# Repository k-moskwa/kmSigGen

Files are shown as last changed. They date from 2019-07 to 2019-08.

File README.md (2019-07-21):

# kmSigGen
DDS Generator based on AD9833 and ATMega8A with WiFi support via ESP8266-01

Main features:
* generates square (5Vp-p), sine and triangle(0.6Vp-p) waves in the ~0.1Hz to 12.5MHz frequency range (with ~0.1Hz step regulation)
* user interface based on LCD 16x2 and single rotary encoder with button
* possibility to store and recall 4 presets
* possibility to control device via TWI/I2C interface
* optional ESP8266-01 module for controlling device via WWW (e.g. from mobile phone)
* localization (available English and Polish language)
* screen saver (when available in LCD)
* easy configuration process with single conifg.h file (with possibility to disable some modules)
* project files available for AtmelStudio7 and Eclipse 

Components:
* ATmega8A MCU @ 8MHz
* AD9833/9837 assembled module @ 25MHz
* LCD 16x2 screen
* rotary encoder with button
* resistors, capacitors, connectors as defined on schematics view
Optional components:
* ESP8266-01 module
* 2 x LED (power and debug)

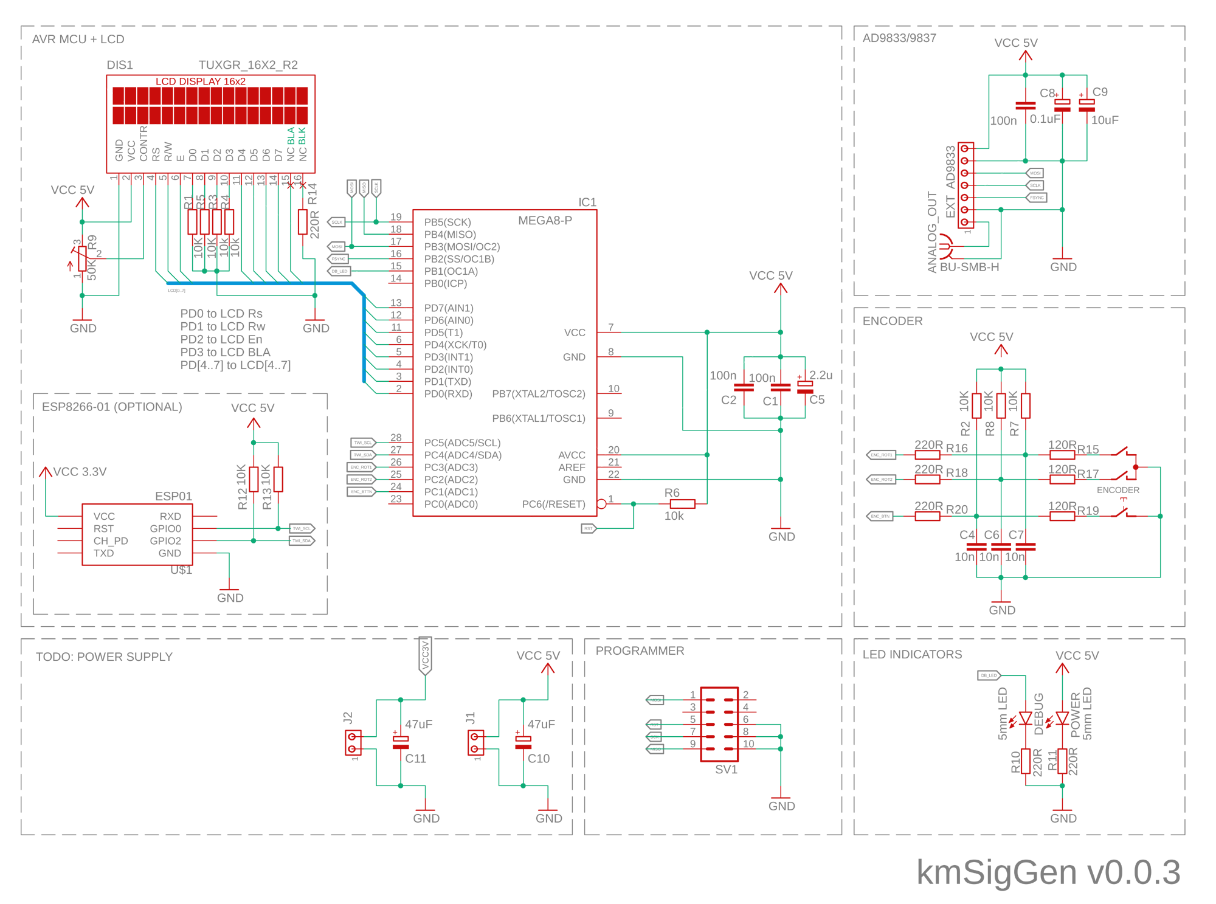
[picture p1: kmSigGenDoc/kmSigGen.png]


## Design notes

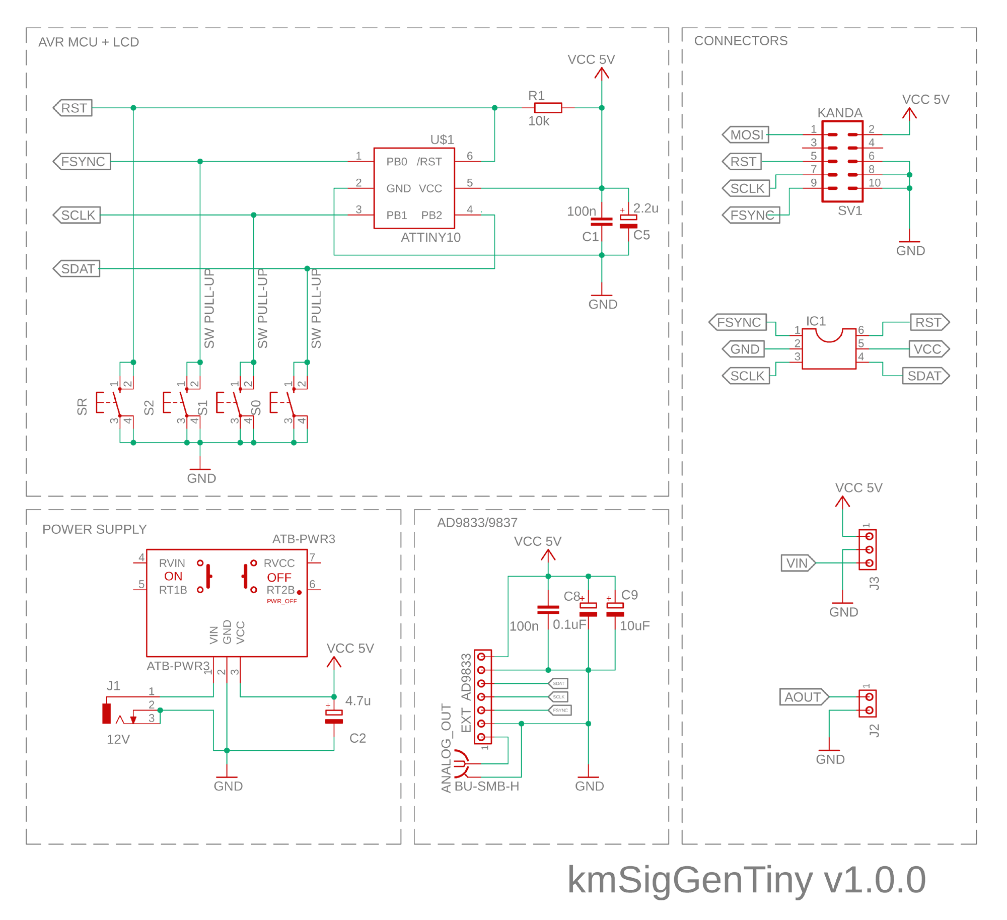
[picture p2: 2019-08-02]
kmSigGenEagle/kmSigGenTiny_Schematics.png

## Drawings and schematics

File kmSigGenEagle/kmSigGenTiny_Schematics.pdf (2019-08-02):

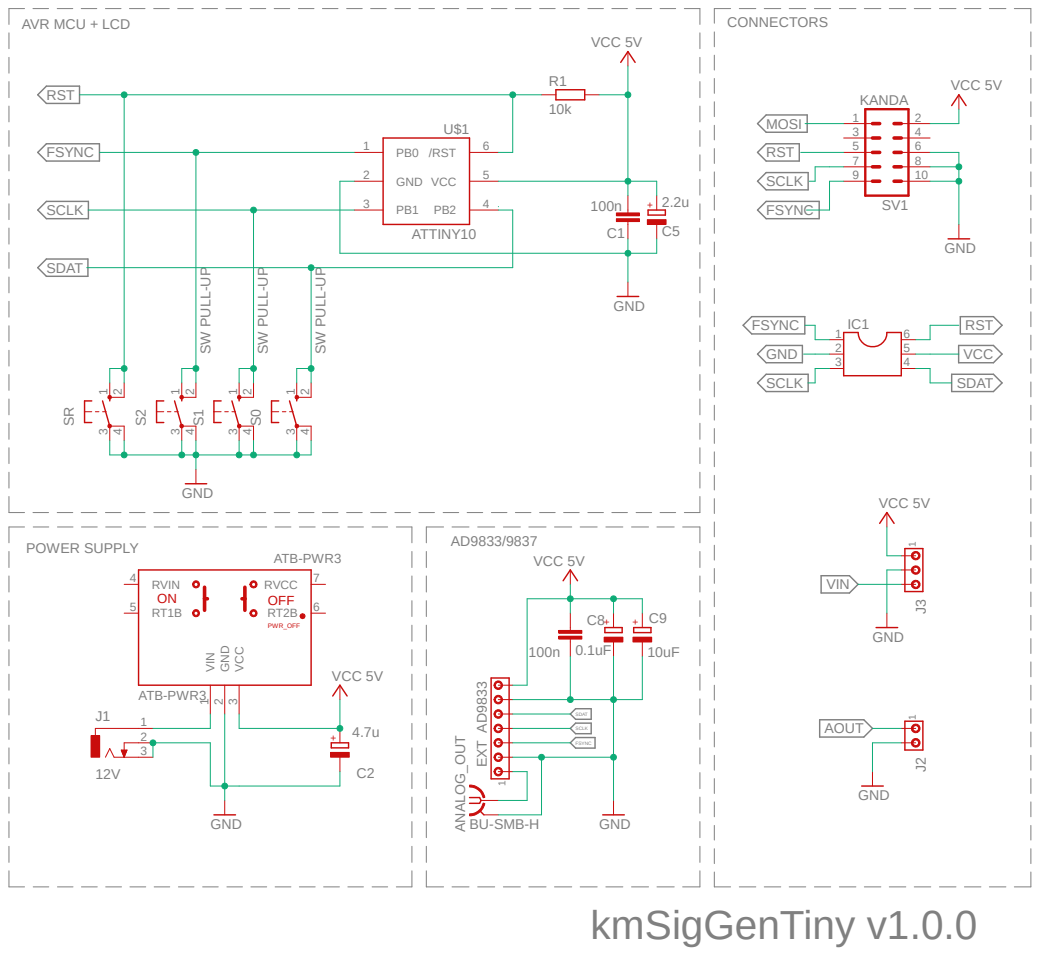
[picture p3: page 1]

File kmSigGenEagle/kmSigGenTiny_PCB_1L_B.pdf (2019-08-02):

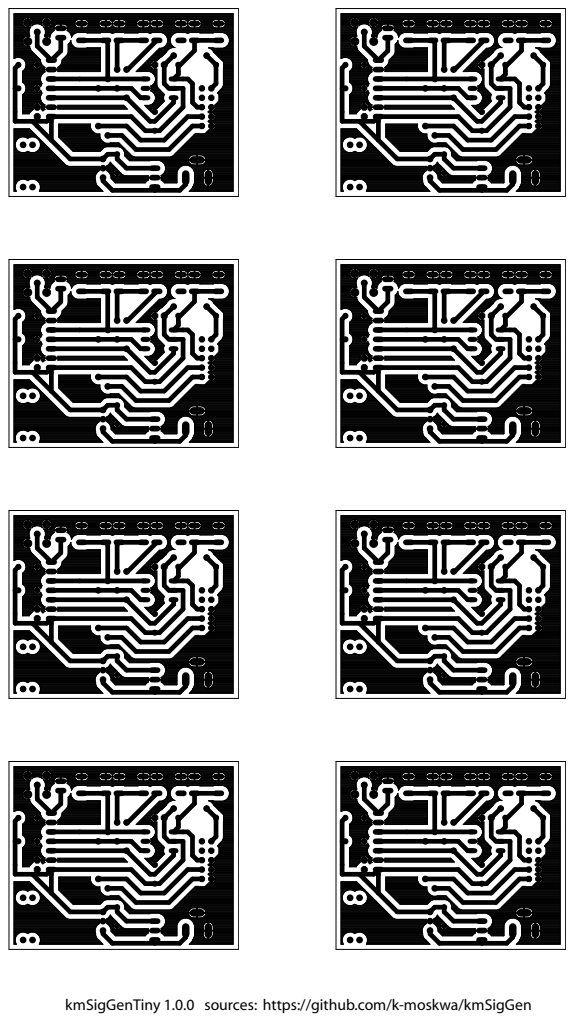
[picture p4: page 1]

kmSigGenTiny 1.0.0 sources: https://github.com/k-moskwa/kmSigGen

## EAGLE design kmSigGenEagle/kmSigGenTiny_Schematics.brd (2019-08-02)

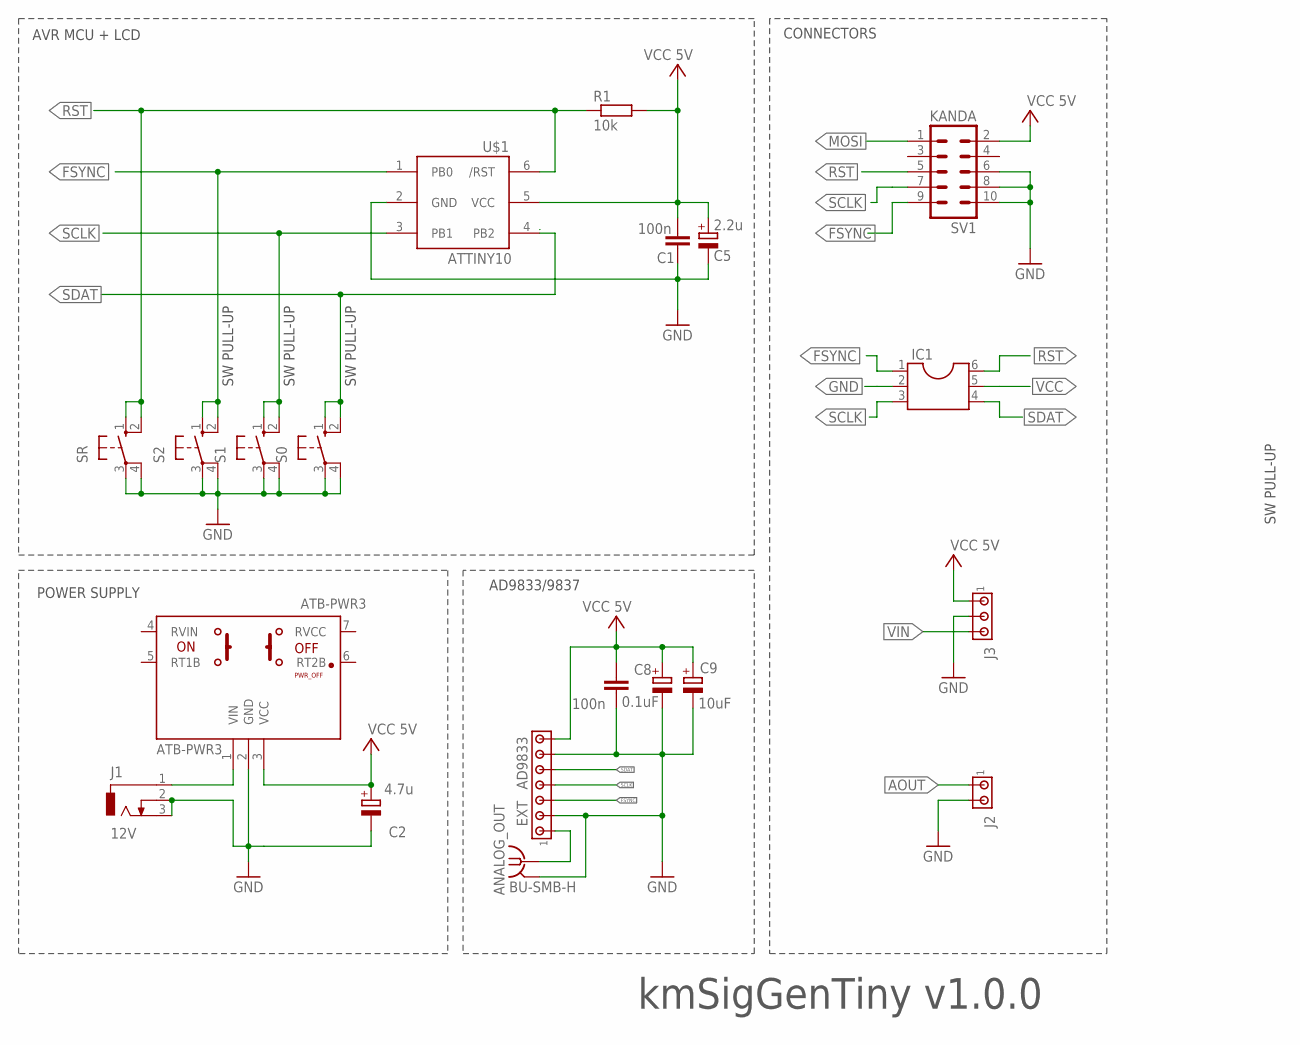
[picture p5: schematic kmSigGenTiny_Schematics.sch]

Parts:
ANALOG_OUT: BU-SMB-H
ATB-PWR3: ATB-PWR3
C1, C3: 100n; C2.5-4
C2: 4.7u; B45181B
C5: 2.2u; B45181B
C8: 0.1uF; B45181B
C9: 10uF; B45181B
EXT: AD9833; 10X07MTA
IC1: DIL6; DIL06
J1: 12V; DCJ0303
J2: MTA02-100; 10X02MTA
J3: MTA03-100; 10X03MTA
R1: 10k; 0207/10
S0, S1, S2: 10-XX; B3F-10XX
SR: 10-XX; B3F-10XX
SV1: KANDA; ML10
U$1: ATTINY10; SOT23-6

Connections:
AOUT: ANALOG_OUT.1, EXT.1, J2.1
FSYNC: EXT.3, IC1.1, S2.1 (S), S2.2 (S1), SV1.9, U$1.1 (PB0)
GND: ANALOG_OUT.2, ANALOG_OUT.3 (2), ANALOG_OUT.4 (2), ANALOG_OUT.5 (2), ATB-PWR3.2 (GND), C1.1, C2.-, C3.1, C5.-, C8.-, C9.-, EXT.2, EXT.6, IC1.2, J1.2, J1.3, J2.2, J3.2, S0.3, S0.4 (P1), S1.3, S1.4 (P1), S2.3, S2.4 (P1), SR.3, SR.4 (P1), SV1.6, SV1.8, SV1.10, U$1.2 (GND)
MOSI: SV1.1
RST: IC1.6, R1.1, SR.1 (S), SR.2 (S1), SV1.5, U$1.6 (/RST)
SCLK: EXT.4, IC1.3, S1.1 (S), S1.2 (S1), SV1.7, U$1.3 (PB1)
SDAT: EXT.5, IC1.4, S0.1 (S), S0.2 (S1), U$1.4 (PB2)
VCC: ATB-PWR3.3 (VCC), C1.2, C2.+, C3.2, C5.+, C8.+, C9.+, EXT.7, IC1.5, J3.1, R1.2, SV1.2, U$1.5 (VCC)
VIN: ATB-PWR3.1 (VIN), J1.1, J3.3

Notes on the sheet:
AD9833/9837
POWER SUPPLY
AVR MCU + LCD
CONNECTORS
kmSigGenTiny v1.0.0
SW PULL-UP

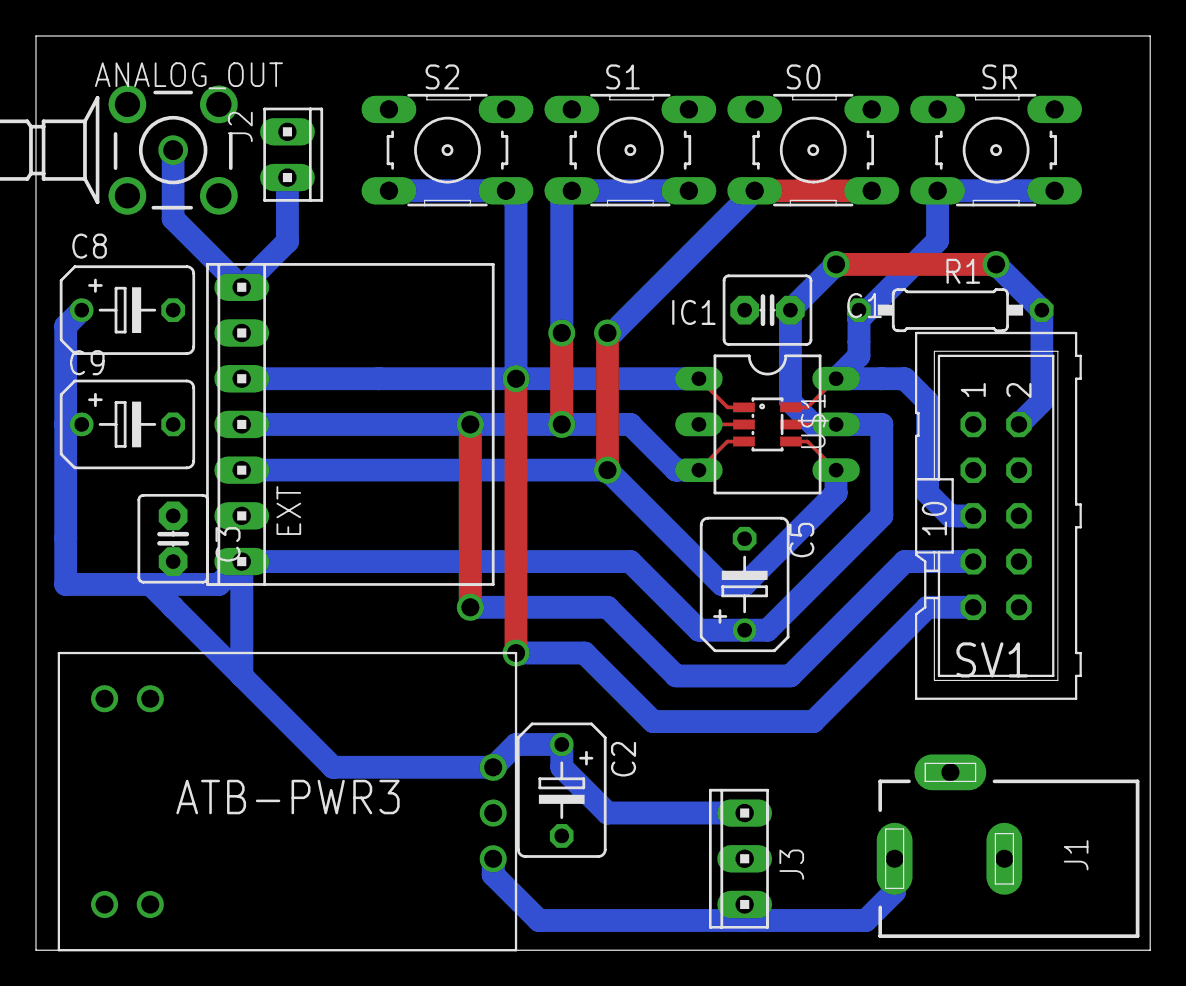
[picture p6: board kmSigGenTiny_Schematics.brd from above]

Board: 2 copper layers, 61.9 x 50.8 mm, 20 parts (0 on the bottom side), 8 nets.

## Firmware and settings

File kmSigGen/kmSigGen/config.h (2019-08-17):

/** @file
 * @brief Configuration preprocessor parameters for kmSigGen project.
 * config.h
 *
 *  Created on: Jul 09, 2019
 *      Author: Krzysztof Moskwa
 *      License: GPL-3.0-or-later
 *
 *  Signal Generator based on AVR ATmega8, AD9833/AD9837 module and LCD display
 *  Copyright (C) 2019  Krzysztof Moskwa
 *
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
 */

#ifndef CONFIG_H_
#define CONFIG_H_

// Enable for default configuration of ATB-ANDROMEDA developbment board
//#define KMSG_ATB

// Enable one available localizations
#define KMSG_LOCALE "localeEn.h"
//#define KMSG_LOCALE "localePl.h"

// EEPROM definition of the ID/VER header
#define KMSG_MAGIC "KMSG100"
// last byte is '\0' so it's 8 bytes
#define KMSG_MAGIC_LENGTH 8
#define KMSG_MAX_PRESETS 5

// Definition of the TWI/I2C address (0xAD >> 1 ;-)
#define TWI_SLAVE_ADDRESS 0x56
#define TWI_BUFFER_LENGTH 12

// Port / pin definition for SPI (communication with AD9833)
#define SG_DDR DDRB
#define SG_PORT PORTB
#define SG_DD_SS	PB2
#define SG_DD_MOSI	PB3
#define SG_DD_MISO	PB4
#define SG_DD_SCK 	PB5

#ifndef KMSG_ATB
#define LCD_DDR DDRD
#define LCD_PORT PORTD
#else
#define LCD_DDR DDRA
#define LCD_PORT PORTA
#endif
#define LCD_COLS 16
#define LCD_ROWS 2
#define STR_INTERNAL_BUFFERS_SIZE_OF LCD_COLS + 1

#define DEBUG_DDR DDRB
#define DEBUG_PORT PORTB
#define DEBUG_PIN PB1
#define DEBUG_STEPS 100

#define BUTTON_DDR DDRC
#define BUTTON_PORT PORTC
#define BUTTON_PORT_IN PINC
#define BUTTON_PIN PC1

#define RSE_DDR DDRC
#define RSE_PORT PORTC
#define RSE_PORT_IN PINC
#define RSE_PIN1 PC2
#define RSE_PIN2 PC3
#define RSE_TICKS_PER_SWITCH 4

// AD9833 master clock in Hz (25MHz default)
#define SG_MCLK 25000000ULL
// Multplier of the frequency provided to calcFreqReg and calcNearestFreq methods (*1000)
#define SG_FREQ_COEF 1000ULL

// Default frequency - 1MHz / SQUARE
#define DEFAULT_FREQUENCY 1000000000
#define DEFAULT_WAVE_TYPE UI_SIG_SQUARE
// Default preset1 - 985 248 Hz / SQUARE
#define DEFAULT_FREQUENCY_PRESET1 985248000
#define DEFAULT_WAVE_TYPE_PRESET1 UI_SIG_SQUARE
// Default preset1 - 1 022 727 Hz / SQUARE
#define DEFAULT_FREQUENCY_PRESET2 1022727000
#define DEFAULT_WAVE_TYPE_PRESET2 UI_SIG_SQUARE
// Default preset1 - 7 881 984 Hz / SQUARE
#define DEFAULT_FREQUENCY_PRESET3 7881984000
#define DEFAULT_WAVE_TYPE_PRESET3 UI_SIG_SQUARE
// Default preset1 - 8181816 Hz / SQUARE
#define DEFAULT_FREQUENCY_PRESET4 8181816000
#define DEFAULT_WAVE_TYPE_PRESET4 UI_SIG_SQUARE

// screen saver enabled after 30 s on the main screen (comment line ot disable screen saver)
#define KMSG_SCREEN_SAVER_TIMEOUT 30000

// splash screen timeout 1.5s
#define KMSG_SPLASH_SCREEN_TIMEOUT 1500

// Misc/internal
// Disable using stdio (e.g. sprintf) and use alternative implementation
#define KMSG_NO_STDIO

// Disable using EEPROM memory routines (settings) and use predefined presets instead
//#define KMSG_NO_EEPROM

// Show approximate frequencies entered by user instead of real frequency from generator
#define KMSG_SHOW_APPROX_FREQ

// Disable TwoWire (I2C) routines so it's not possible to control module from external interface
//#define KMSG_NO_TWI

// Disable internal debug features
#define KMSG_NO_PIN_DEBUG

// In case of debug environment - disable some modules so application fits in FLASH space
// (use settings from above for release)
// NOTE: Do not change this part unless really necessary
#ifdef DEBUG
#define KMSG_NO_TWI
#define KMSG_NO_EEPROM
#endif

#endif /* CONFIG_H_ */

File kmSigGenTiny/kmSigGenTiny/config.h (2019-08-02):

/*
 * config.h
 *
 *  Created on: Jul 09, 2019
 *      Author: Krzysztof Moskwa
 *      License: GPL-3.0-or-later
 *
 *  Signal Generator based on AVR ATmega8, AD9833/AD9837 module and LCD display
 *  Copyright (C) 2019  Krzysztof Moskwa
 *
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
 */

#ifndef CONFIG_H_
#define CONFIG_H_

#define CCP_SIGNATURE 0xD8
#define TINY_MCLK_8MHZ 0

#define SG_DDR		DDRB
#define SG_PORT		PORTB
#define SG_DD_SS	PB0
#define SG_DD_SCK 	PB1
#define SG_DD_MOSI	PB2
#define SG_SOFT_CLK_DELAY_US 1

#define BUTTON_DDR DDRB
#define BUTTON_PORT PORTB
#define BUTTON_PORT_IN PINB
#define BUTTON_PIN_0 PB0
#define BUTTON_PIN_1 PB1
#define BUTTON_PIN_2 PB2

// AD9833 master clock in Hz (25MHz default)
#define SG_MCLK 25000000ULL
// Multplier of the frequency provided to calcFreqReg and calcNearestFreq methods (*1000)
#define SG_FREQ_COEF 1000ULL
// Bits in word sent via SPI to AD9833 chip
#define AD9833_WORD_SIZE 16

// Default preset1 - 985 248 Hz / SQUARE
#define DEFAULT_FREQUENCY_PRESET1 985248000
#define DEFAULT_WAVE_TYPE_PRESET1 SG_SIG_SQUARE
// Default preset2 - 1 022 727 Hz / SQUARE
#define DEFAULT_FREQUENCY_PRESET2 1022727000
#define DEFAULT_WAVE_TYPE_PRESET2 SG_SIG_SQUARE
// Default preset3 - 7 881 984 Hz / SQUARE
#define DEFAULT_FREQUENCY_PRESET3 7881984000
#define DEFAULT_WAVE_TYPE_PRESET3 SG_SIG_SQUARE
// Default preset4 - 8 181 816 Hz / SQUARE
#define DEFAULT_FREQUENCY_PRESET4 8181816000
#define DEFAULT_WAVE_TYPE_PRESET4 SG_SIG_SQUARE
// Default preset5 - 1 843 200 Hz / SQUARE
#define DEFAULT_FREQUENCY_PRESET5 1843200000
#define DEFAULT_WAVE_TYPE_PRESET5 SG_SIG_SQUARE
// Default preset6 - 3 686 400 Hz / SQUARE
#define DEFAULT_FREQUENCY_PRESET6 3686400000
#define DEFAULT_WAVE_TYPE_PRESET6 SG_SIG_SQUARE
// Default preset7 - 7 372 800 Hz / SQUARE
#define DEFAULT_FREQUENCY_PRESET7 7372800000
#define DEFAULT_WAVE_TYPE_PRESET7 SG_SIG_SQUARE
// Default preset8 -11 059 200 Hz / SQUARE
#define DEFAULT_FREQUENCY_PRESET8 11059200000
#define DEFAULT_WAVE_TYPE_PRESET8 SG_SIG_SQUARE
// Default frequency - 1MHz / SQUARE
#define DEFAULT_FREQUENCY DEFAULT_FREQUENCY_PRESET1
#define DEFAULT_WAVE_TYPE DEFAULT_WAVE_TYPE_PRESET1

#define AD9833_COEF_BIN 28
#define AD9833_COEF _BV(AD9833_COEF_BIN)

#define CALC_FIX ((((uint64_t)SG_MCLK * (uint64_t)SG_FREQ_COEF) >> AD9833_COEF_BIN) >> 1)

#define FREQUENCY_REG_PRESET1 (uint32_t)(((((uint64_t)DEFAULT_FREQUENCY_PRESET1 << AD9833_COEF_BIN) / (uint64_t)SG_MCLK) + CALC_FIX ) / SG_FREQ_COEF)
#define FREQUENCY_REG_PRESET2 (uint32_t)(((((uint64_t)DEFAULT_FREQUENCY_PRESET2 << AD9833_COEF_BIN) / (uint64_t)SG_MCLK) + CALC_FIX ) / SG_FREQ_COEF)
#define FREQUENCY_REG_PRESET3 (uint32_t)(((((uint64_t)DEFAULT_FREQUENCY_PRESET3 << AD9833_COEF_BIN) / (uint64_t)SG_MCLK) + CALC_FIX ) / SG_FREQ_COEF)
#define FREQUENCY_REG_PRESET4 (uint32_t)(((((uint64_t)DEFAULT_FREQUENCY_PRESET4 << AD9833_COEF_BIN) / (uint64_t)SG_MCLK) + CALC_FIX ) / SG_FREQ_COEF)
#define FREQUENCY_REG_PRESET5 (uint32_t)(((((uint64_t)DEFAULT_FREQUENCY_PRESET5 << AD9833_COEF_BIN) / (uint64_t)SG_MCLK) + CALC_FIX ) / SG_FREQ_COEF)
#define FREQUENCY_REG_PRESET6 (uint32_t)(((((uint64_t)DEFAULT_FREQUENCY_PRESET6 << AD9833_COEF_BIN) / (uint64_t)SG_MCLK) + CALC_FIX ) / SG_FREQ_COEF)
#define FREQUENCY_REG_PRESET7 (uint32_t)(((((uint64_t)DEFAULT_FREQUENCY_PRESET7 << AD9833_COEF_BIN) / (uint64_t)SG_MCLK) + CALC_FIX ) / SG_FREQ_COEF)
#define FREQUENCY_REG_PRESET8 (uint32_t)(((((uint64_t)DEFAULT_FREQUENCY_PRESET8 << AD9833_COEF_BIN) / (uint64_t)SG_MCLK) + CALC_FIX ) / SG_FREQ_COEF)

#endif /* CONFIG_H_ */

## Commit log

2019-07-21 Fixed issue with clearing wavetype after updating frequency from WiFi module; cleanup of Eagle Schematics, version changed to 1.0.1
    [kmSigGen_Schematics.sch]
2019-07-21 Updated schematics of encoder hardware
    [kmSigGen_Schematics.sch]
2019-07-21 Updatech schematics of encoder hardware
    [kmSigGen_Schematics.sch]
2019-07-23 Solved issue with ESP8266 startup information; changed default colale to english version
    [config.h]
2019-07-27 Added power supply and update of schematics after review (thx. Zealota & mirekk36 from http://forum.atnel.pl)
    [kmSigGen_Schematics.sch]
2019-08-02 Added signal generator based on ATtiny10
    [kmSigGenTiny_Schematics.brd, kmSigGenTiny_Schematics.sch]
2019-08-07 Solved potential source of problems when backlight pin is changed to different value (thx. anat from forum.atnel.com for helping to find it) + minor fixes
2019-08-17 KMSG-001 Added Support for ATB-ANDROMEDA development board

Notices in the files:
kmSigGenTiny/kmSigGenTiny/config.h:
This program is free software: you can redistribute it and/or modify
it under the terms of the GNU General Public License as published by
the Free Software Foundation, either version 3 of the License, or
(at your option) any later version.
